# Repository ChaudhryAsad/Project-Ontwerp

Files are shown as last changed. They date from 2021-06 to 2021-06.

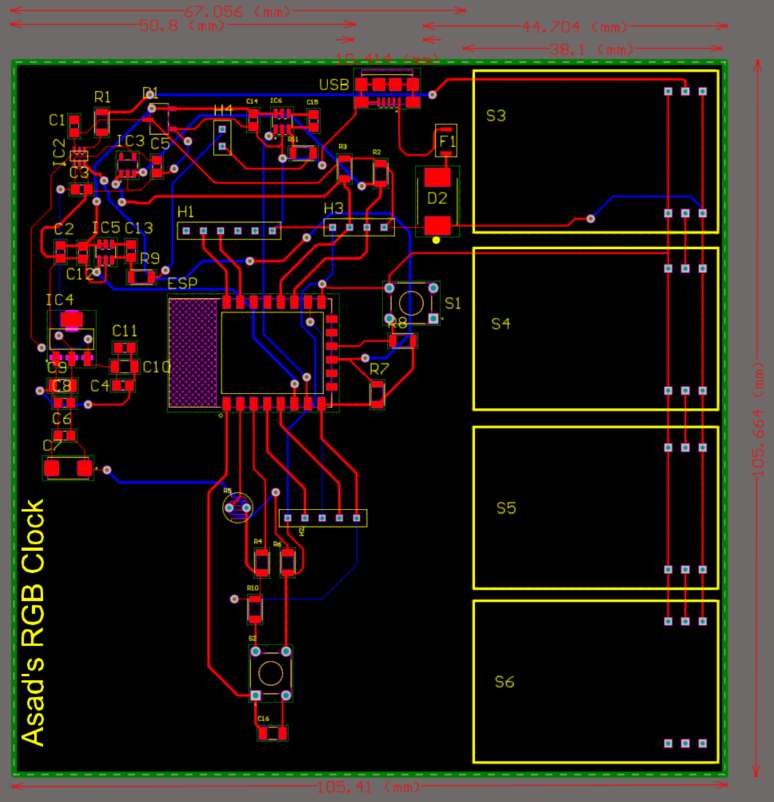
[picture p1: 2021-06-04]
English/foto's/Pcb_2d.PNG

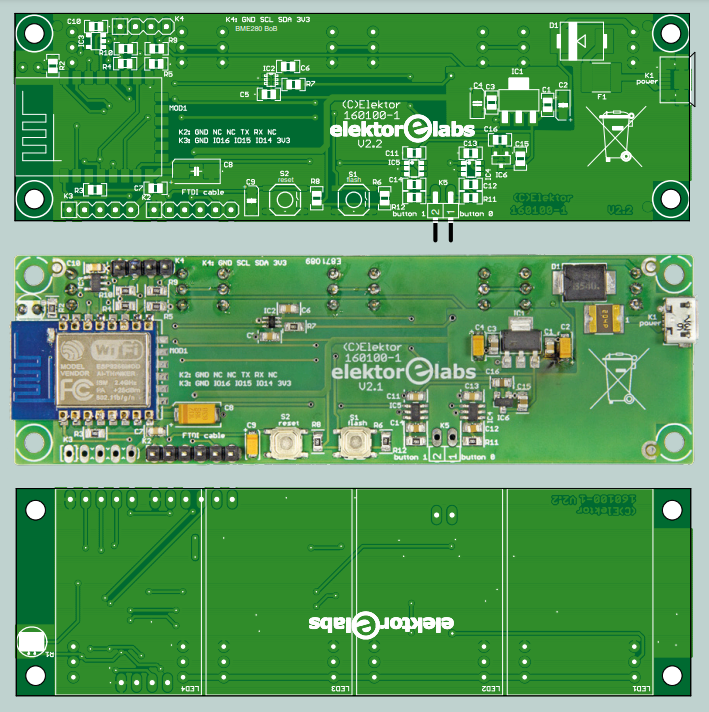
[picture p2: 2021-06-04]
Altium/PCB.PNG

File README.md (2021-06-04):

# Project-Ontwerp_2021-2022
## RGBDigit Clock
The project started with the question “What are the minimal requirements to design a system that is both safe and user friendly - for an RGB Digit Clock”. The content of the application note is the methods used for the project, the Information about the materials and it also includes the result.

This project RGB Digit Clock which means the clock can change into many colours. If we connect a BME280 break-out board (BoB), then it is possible for this circuit to also display temperature, humidity, or air pressure very well. It is an interesting piece of equipment that has many useful functions, it is definitely worth taking a deeper look at. In the course of this project, the following auxiliary materials were used as a starting point: Elektor magazine.

The application note is structured as follows. All the materials and methods that are used can be found/retrieved. This chapter also explains the purpose of each component.

##	Material and methods

### Esp-12
The clock is controlled by an ESP12 module, so it can be synchronized with a time server on the Internet, con-trolled with a mobile device or computer in the network, or receive sensor data via Wi-Fi. 



### Multi-colour 7-segment

This display has eight 5050-RGB NeoPixel LEDs (seven segments plus decimal point) with integrated three-chip chips, allowing the user to control the color and brightness of each individual segment via a 3-wire bus (VCC, GND, and DATA). 



## PCB Design

Pcb_3d

## Built With

* [Arduino IDE](https://www.arduino.cc/en/Main/Software/)       - Programming environment used for the Arduino
* [ALtium](https://www.altium.com/)                             - For the Schematic and PCB design
* [Autocad](https://www.autodesk.com/products/autocad/overview?term=1-YEAR)                             - For 3d desgin of the case

## Component List/Price



## Reference list 
https://www.elektor.com/rgb-digit-clock-module-160100-91



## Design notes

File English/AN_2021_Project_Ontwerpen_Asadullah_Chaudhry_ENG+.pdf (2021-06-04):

# ELEKTRONICA-ICT

## Project Ontwerpen

# RGBDigit Clock

Author Asadullah Chaudhry

## 1 Content

1 / 6

ELECTRONICS-ICT | Project Design 2020-2021

## 2 Introduction

The project started with the question “What are the least requirements to design a system that is both safe and user friendly for an RGB Digit Clock”. The content of the application note has the methods used for the project, the Information about the materials and it also includes the result.

This project is about RGB Digit Clock which means the clock can change into many colors. If we connect a BME280 break-out board (BoB) then it is possible for this circuit to also display temperature, humidity, or air pressure very well. It is an interesting piece of equipment that has many useful functions, it is definitely worth taking a deeper look at. In the course of this project, the following auxiliary materials were used as a starting point: Elektor magazine.

The application note is structured as follows. Later to this introduction, all the materials and methods that are used can be found/retrieved. This chapter also explains the purpose of each component.

Project Development: RGBDigit Clock | 2 / 6

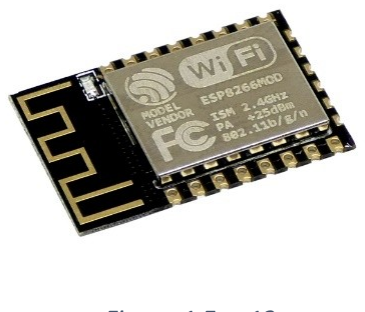
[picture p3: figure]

Figuur 1 Esp-12

Figuur 2 7-Segtment

## 3 Material and methods

### 3.1 ESP-12

The clock is controlled by an ESP12 module, so it can be synchronized with a time server on the Internet, controlled with a mobile device or computer in the network, or receive sensor data via Wi-Fi. [1]

## ESP-12 is a miniature Wi-Fi module present in the market and is used for establishing a wireless network connection for microcontroller or processor. [2]

### 3.2 Arduino IDE

The Arduino Integrated Development Environment (IDE) is a cross-platform application (for Windows, macOS, Linux) that is written in functions from C and C++. It is used to write and upload programs to Arduino compatible boards, but also, with the help of third-party cores, other vendor development boards.

In this project, it will be used to write the main software of the RGBDigit Clock. There are a lot of libraries and support online for this IDE what makes it easier to write the desired code.

### 3.3 Multi-color 7-segment

This display has eight 5050-RGB NeoPixel LEDs (seven segments plus decimal point) with integrated three-chip chips, allowing the user to control the color and brightness of each individual segment via a 3-wire bus (VCC, GND, and DATA). Up to 10 displays can be strung together via the DATA IN and DATA OUT pins. Each LED of a NeoPixel emits a primary color (R, G, or B). And each LED can be set to 256 brightness levels, resulting in an astonishing 256 x 256 x 256 = 16,777,216 possible colors for each segment.

### 3.4 Schematic

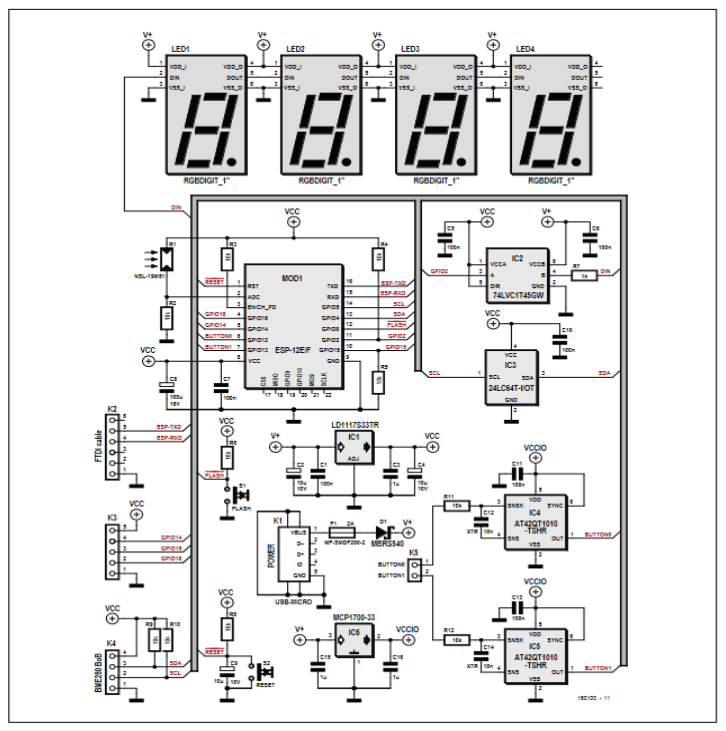
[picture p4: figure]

Figuur 3 RGB Digit Clock schematic

In the figure 2, we see the full scheme of this project. The clock is powered with 5 V via micro USB connector K1. The power supply is protected by fuse F1, a 2A self-resetting fuse with a PTC. Schottky diode D1 protects the circuit against polarity reversal. IC1 is the 3.3V voltage regulator for most of the circuit and IC6 is the voltage regulator for the Qtouch touch sensors IC4 and IC5 (which have a separate power supply to prevent interference). The two touch sensors Button0 and Button1 are used to control the display mode of the clock. S1 and S2 are used only for clock resetting and firmware flashing IC2 serve as a level adjuster between the 3.3V of the ESP-12E and the power supply (about 4.5V) of the displays. In EEPROM IC3 the clock settings are saved in the event of a power failure and LDR R1 is used to dim the displays in the dark. On K2, a 3.3V-FTDI cable (or another 3.3V-USB UART) be connected to flash the ESP-12E module; it can also be used for debugging applications. Via K3, the 3.3V power supply, and three I / O pins of the ESP12E are accessible for inhouse developments and/or future expansions.

### 3.5 Flowdiagram

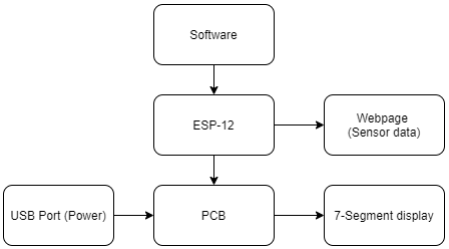
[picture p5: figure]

Figuur 3: Flowchart RGBDigit

### 3.6 Component list

Component type | Value | Quantity | Ordered from
Resistor (R1) | LDR NSL-19M51 | 1 | Aliexpress
Resistor (R2 - R12) | 10KΩ | 10 | Aliexpress
Resistor (R7) | 1KΩ | 1 | Aliexpress
Capacitors (C1,C5,C6,C7,C10,C11,C13) | 100nF, 50V, X7R, 0805 | 7 | octopart.com
Capacitors (C2,C4,C9) | 10µF, 10V, tantalum, 1206 | 3 | octopart.com
Capacitors (C3,C15,C16) | 1µF, 50 V, X5R, 0805 | 3 | Gotron
Capacitors (C8) | 100µF, 16V, 2312 | 1 | Gotron
Capacitors (C12,C14) | 10nF, 50V, X7R, 0805 | 2 | Gotron
Semiconductors (D1) | MBRS540 | 1 | Gotron
Led's | 7-segment RGB display | 4 | microelectronics
IC1 | LD1117S33TR | 1 | microelectronics
IC2 | 74LVC1T45GW | 1 | microelectronics
IC3 | EEPROM 8K × 8 bit, type 24LC64T- I/OT | 1 | microelectronics
IC4,IC5 | Qtouch Touch Sensor type AT42QT1010-TSHR | 1 | microelectronics
IC6 | MCP1700T-3302E/TT | 1 | microelectronics
Fuse (F1) | 2A PTC resettable fuse, type MF- SMDF200-2 | 1 | microelectronics
Micro-USB | Micro-USB type B receptacle, underside mount | 1 | microelectronics
Header | 6-pin SIL pinheader, 0.1” pitch, right angled | 1 | microelectronics
Header | 5-pin SIL pinheader, 0.1” pitch, right angled | 1 | microelectronics
Header | 4-pin SIL pinheader, 0.1” pitch, straight | 1 | microelectronics
Header | 2-pin SIL pinheader, 0.1” pitch, right angled | 1 | microelectronics
Micro controller | ESP8266-12F | 1 | Aliexpress
Switch (S1) | Tactile switch | 1 | microelectronics

## 3 Reference list

[1] C. d. Bruijn, „RGB clock,” https://www.elektormagazine.com/, Nederland, 2017.
[2] „ESP-12E - WiFi Module,” https://components101.com/wireless/esp12e-pinout-datasheet#:~:text=ESP %2D12E%20is%20a%20miniature,SoC%20(System%20on%20Chip)., 17 October, 2018.

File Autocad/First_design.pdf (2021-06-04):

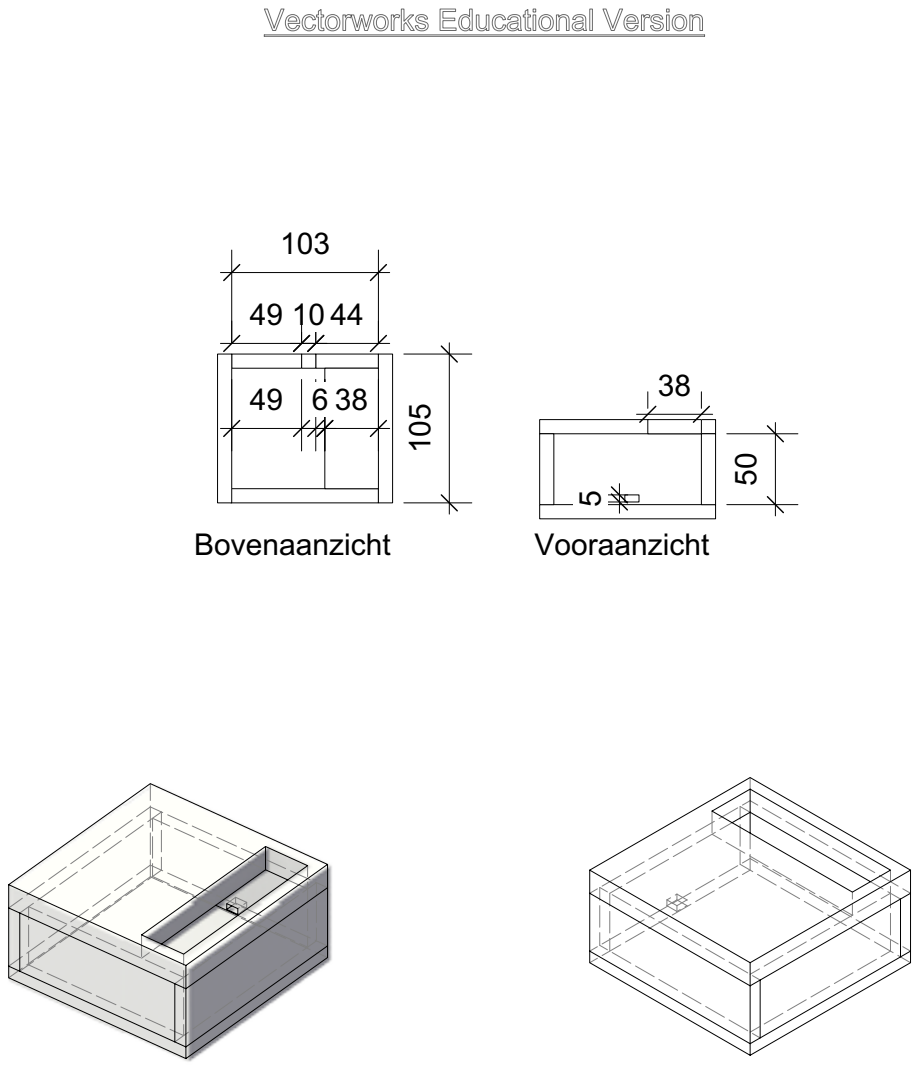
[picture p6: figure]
Bovenaanzicht; 5 Vooraanzicht; Vectorworks Educational Version

Vectorworks Educational Version

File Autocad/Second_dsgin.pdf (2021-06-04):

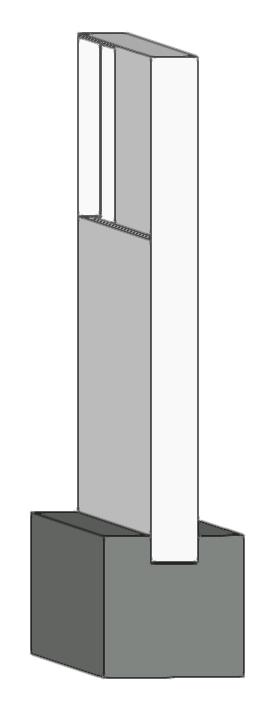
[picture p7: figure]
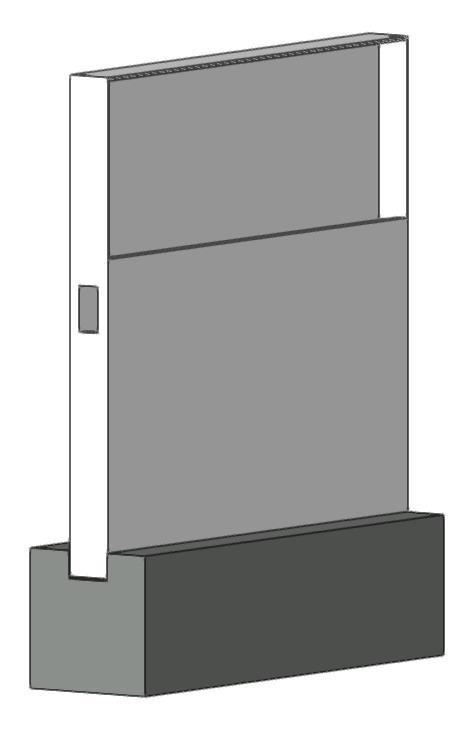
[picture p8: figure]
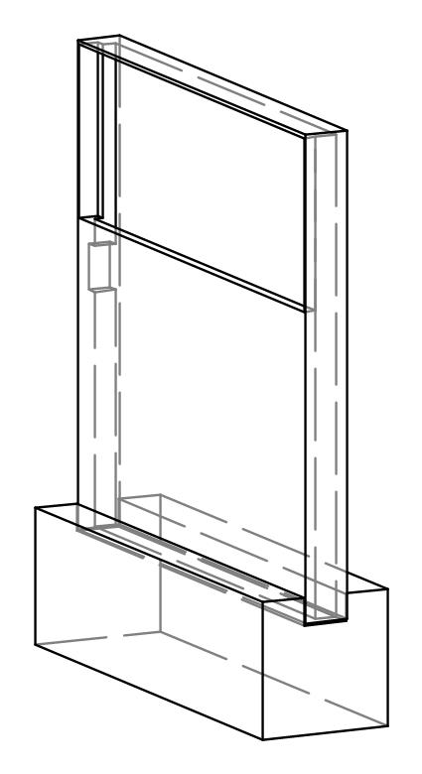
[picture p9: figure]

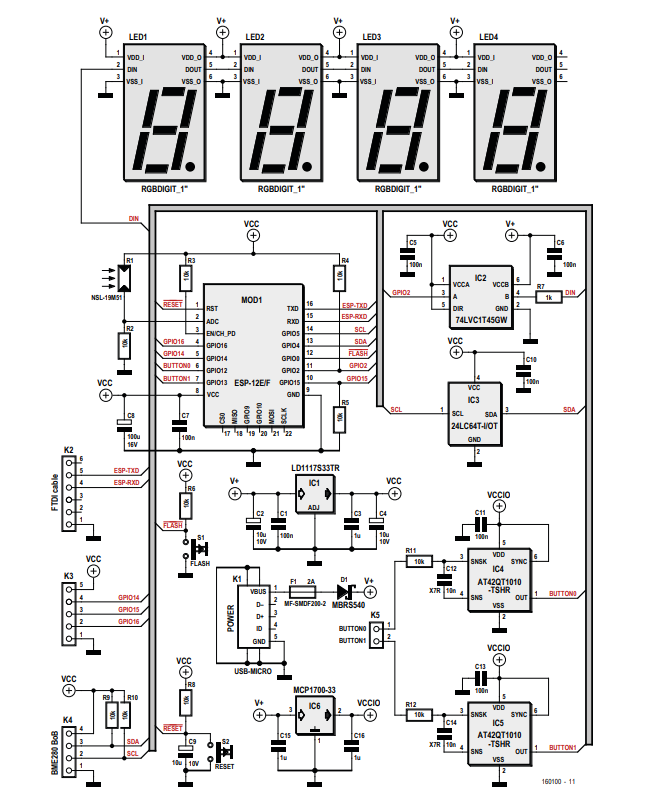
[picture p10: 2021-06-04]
Altium/Schematic.PNG

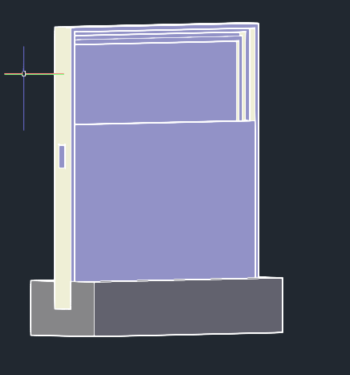
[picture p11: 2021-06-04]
English/foto's/case.PNG

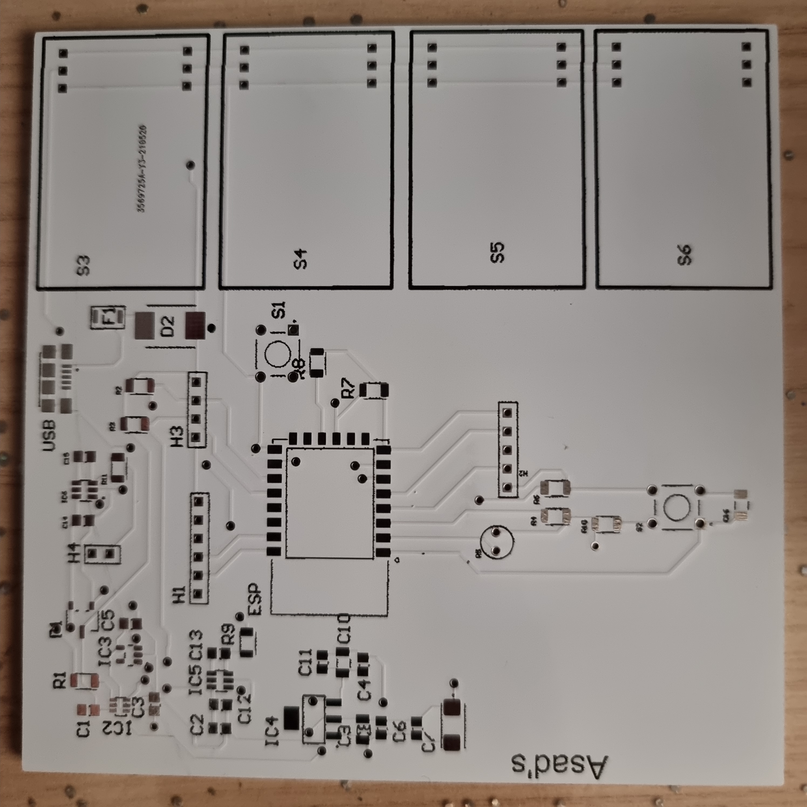
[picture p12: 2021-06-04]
English/foto's/Pcb_leeg.jpeg

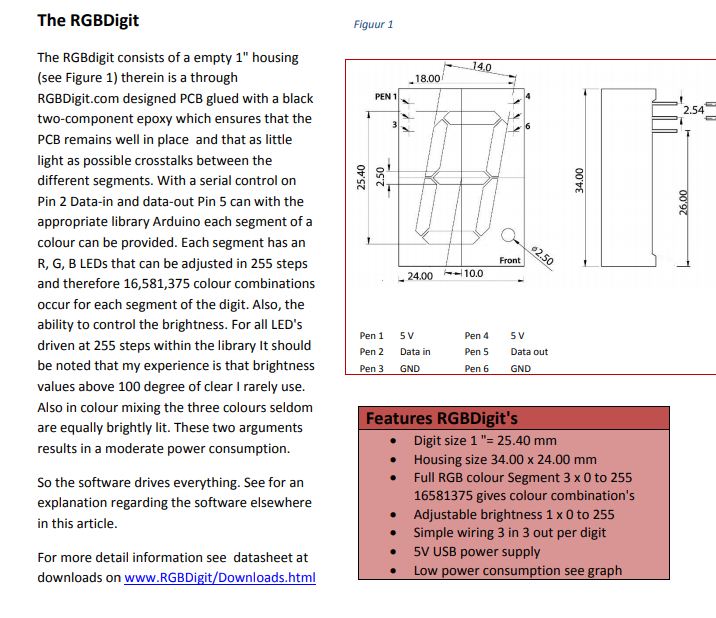
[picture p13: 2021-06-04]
Altium/RGB_digit.PNG

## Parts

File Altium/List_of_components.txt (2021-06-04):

Component List
Resistors
R1 = LDR NSL-19M51*
R2,R3,R4,R5,R6,R8,R9,R10,R11,R12 = 10kOhm
R7 = 1kOhm
Capacitors
C1,C5,C6,C7,C10,C11,C13 = 100nF, 50V, X7R, 0805
C2,C4,C9 = 10µF, 10V, tantalum, 1206
C3,C15,C16 = 1µF, 50 V, X5R, 0805
C8 = 100µF, 16V, 2312
C12,C14 = 10nF, 50V, X7R, 0805
Semiconductors
D1 = MBRS540
LED1,LED2,LED3,LED4 = 7-segment RGB display*
IC1 = LD1117S33TR
IC2 = 74LVC1T45GW
IC3 = I2C EEPROM 8K × 8 bit, type 24LC64T-I/OT
IC4,IC5 = Qtouch Touch Sensor type AT42QT1010-TSHR
IC6 = MCP1700T-3302E/TT
Miscellaneous
F1 = 2A PTC resettable fuse, type  (Bourns)
K1 = Micro-USB type B receptacle, underside mount
K2 = 6-pin SIL pinheader, 0.1” pitch, right angled
K3 = 5-pin SIL pinheader, 0.1” pitch, right angled
K4 = 4-pin SIL pinheader, 0.1” pitch, straight
K5 = 2-pin SIL pinheader, 0.1” pitch, right angled
MOD1 = ESP8266-12F
S1 = Tactile switch

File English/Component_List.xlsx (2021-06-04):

Component List
Project Engineer: Asadullah Chaudhry
Component type | Value | Quantity | Ordered from | Orderd | price | Total
Resistor (R1) | LDR NSL-19M51 | 1 | mouser | 2 | €1.15 | €2.30
Resistor (R2 - R12) | 10KΩ | 10 | mouser | 15 | €0.10 | €1.59
Resistor (R7) | 1KΩ | 1 | mouser | 2 | €0.19 | €0.39
Capacitors (C1,C5,C6,C7,C10,C11,C13) | 100nF, 50V, X7R, 0805 | 7 | mouser | 10 | €0.28 | €2.82
Capacitors (C2,C4,C9) | 10µF, 10V, tantalum, 1206 | 3 | mouser | 4 | €0.94 | €3.80
Capacitors (C3,C15,C16) | 1µF, 50 V, X5R, 0805 | 3 | mouser | 4 | €0.94 | €3.80
Capacitors (C8) | 100µF, 16V, 2312 | 1 | Gotron | 1 |  | €1.30
Capacitors (C12,C14) | 10nF, 50V, X7R, 0805 | 2 | mouser | 4 | €0.94 | €3.80
Semiconductors (D1) | MBRS540 | 1 | mouser | 2 | €0.47 | €0.39
Led's | 7-segment RGB display | 4 | mouser | 4 |  | €43.00
IC1 | LD1117S33TR | 1 | mouser | 2 | €0.50 | €1.00
IC2 | 74LVC1T45GW | 1 | mouser | 2 | €0.37 | €0.72
IC3 | EEPROM 8K × 8 bit, type 24LC64T-I/OT | 1 | mouser | 2 | €0.60 | €1.20
IC4,IC5 | Qtouch Touch Sensor type AT42QT1010-TSHR | 1 | mouser | 2 | 0.15 | €0.30
IC6 | MCP1700T-3302E/TT | 1 | mouser | 4 | €0.57 | €2.28
Fuse (F1) | 2A PTC resettable fuse, type MF-SMDF200-2 | 1 | mouser | 2 | €0.47 | €0.94
Micro-USB | Micro-USB type B receptacle, underside mount | 1 | mouser | 2 | €0.80 | €1.60
Header | 6-pin SIL pinheader, 0.1” pitch, right angled | 1 | mouser | 2 | €0.15 | €0.30
Header | 5-pin SIL pinheader, 0.1” pitch, right angled | 1 | mouser | 2 | €0.25 | €0.50
Header | 4-pin SIL pinheader, 0.1” pitch, straight | 1 | mouser | 2 | €0.15 | €0.30
Header | 2-pin SIL pinheader, 0.1” pitch, right angled | 1 | mouser | 2 | €0.15 | €0.30
Micro controller | ESP8266-12F | 1 | Gotron | 1 |  | €6.50
Switch (S1) | Tactile switch | 2 | mouser | 2 | €0.55 | €1.10
Headers for 7-segment | 3-pin | 24 | Gotron |  |  | €2.00
PCB |  | 5x | JLCPCB | 10x |  | €50
Case 3d print |  | 1 |  | 1 |  | €10
Totaal |  |  |  |  |  | €142.23

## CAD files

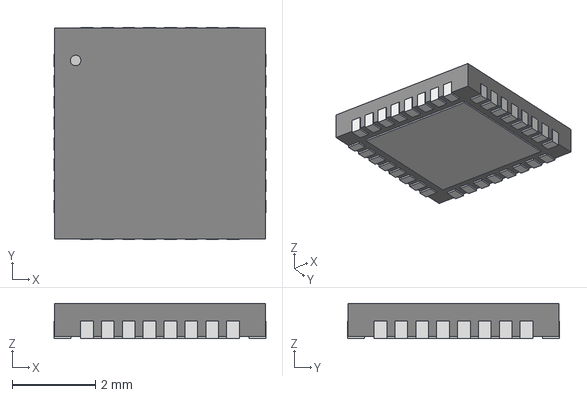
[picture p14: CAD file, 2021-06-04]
Altium/Libarary/AltiumDesigner/2021-03-17_08-27-32/QFN_2491_ADA.step
5.08 x 5.08 x 0.841 mm

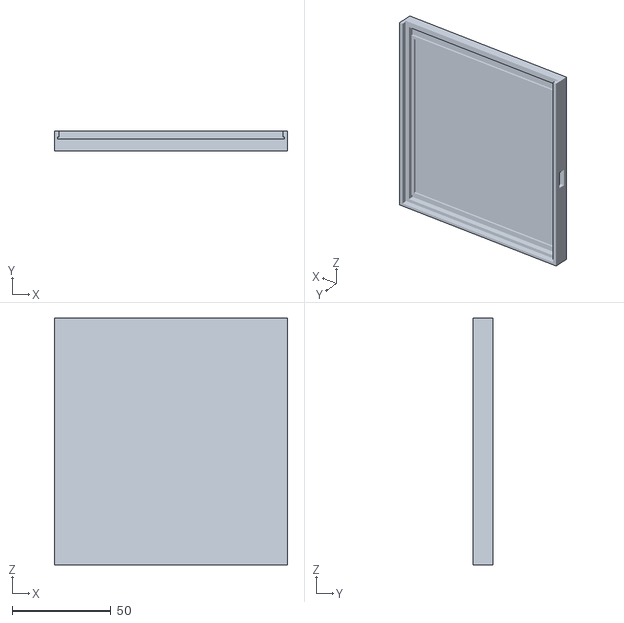
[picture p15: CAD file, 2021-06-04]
Autocad/stl/Part2.STL
118.0 x 10.0 x 125.0

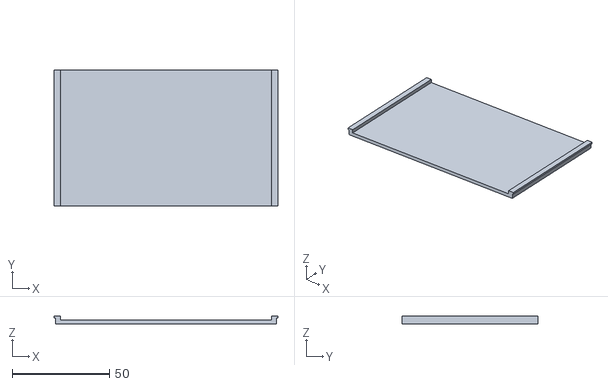
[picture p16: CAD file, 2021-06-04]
Autocad/stl/slder.STL
115.0 x 70.0 x 4.00

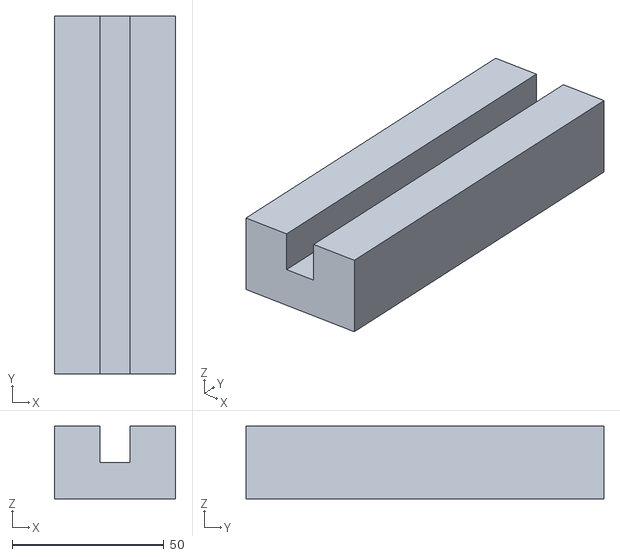
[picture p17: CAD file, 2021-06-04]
Autocad/stl/foot.STL
40.0 x 118.0 x 24.0

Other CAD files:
Autocad/Autocad_3d_Pcb/Assembly.dwg
Autocad/Autocad_3d_Pcb/foot.dwg
Autocad/Logo/LOGO 2D.dwg
Autocad/Autocad_3d_Pcb/Drawing2.dwg
Autocad/Autocad_3d_Pcb/sliding lid.dwg

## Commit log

2021-06-04 Altium
    All the needed files are added in this Repo
    [2021-03-17_08-27-32.PcbLib, 2021-03-17_08-27-32.SchLib, Asad's RGB Clock.PrjPcb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]
2021-06-04 Autocad
    All the needed files are in this repo
    [Assembly.dwg, Drawing2.dwg, LOGO 2D.dwg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]
2021-06-04 English
    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
    [Component_List.xlsx]
